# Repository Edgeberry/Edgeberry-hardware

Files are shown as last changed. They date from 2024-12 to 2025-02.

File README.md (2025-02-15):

Edgeberry banner

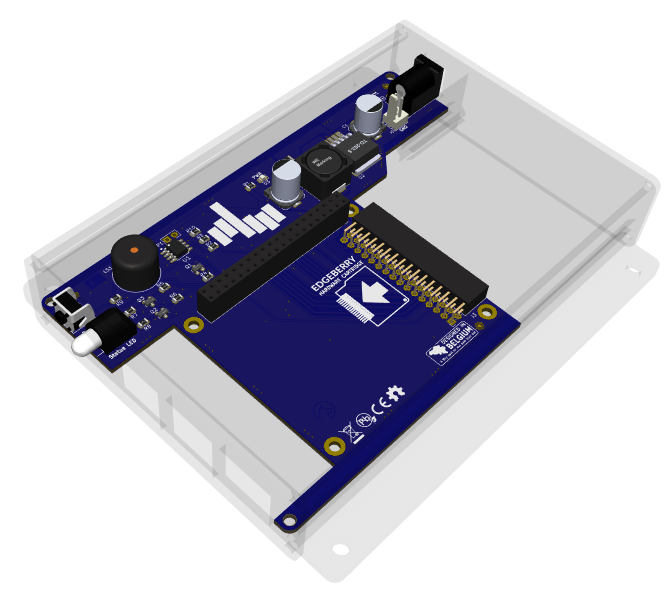
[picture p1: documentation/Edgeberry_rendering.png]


The **Edgeberry Base Board** provides essential additional functionality for deploying the Raspberry Pi Model B as an IoT edge device in a real-world environment.

- **12 to 24VDC input power supply** for reliably powering the device with up to 3A at 5V.
- **Indicators and button** for providing status feedback and device interaction
- **Expansion slot** for Edgeberry Hardware Cartridges
- **Robust enclosure** for withstanding the environmental challenges of the real world
<br/>
<br clear="right"/>

## Edgeberry Device Software
For using your Edgeberry hardware with the Edgeberry ecosystem (e.g. the Edgeberry Dashboard), you'll need to install the [Edgeberry Device Software](https://github.com/Edgeberry/Edgeberry/). Follow [these installation steps](https://github.com/Edgeberry/Edgeberry?tab=readme-ov-file#installation). If you have different plans with this board, this software is not required for correct operation of any of its hardware components.

## (re)Writing the EEPROM
>[!important]
>**When you purchased the Edgeberry Hardware, the manufacturer has written the EEPROM**. If you are the manufacturer, or you're hacking your Edgeberry board, then continue with the following steps.

1) Close the `write protection` jumper (JP1) on the Edgeberry Hardware to enable writing the EEPROM
2) Download and build the [Raspberry Pi Hat eeprom utils](https://github.com/raspberrypi/hats) on your device 
3) Make the EEPROM file from the eeprom_settings.txt using `eepmake` <br> e.g. `$ ./eepmake eeprom_settings.txt edgeberry.eep`
4) Flash the EEPROM using `eepflash.sh` <br> e.g. `$ sudo ./eepflash -w -t=24c256 -f=edgeberry.eep`
5) Now `reboot` the device and check the device tree for your hat's settings <br> e.g. `$ cat /proc/device-tree/hat/vendor`)

## License & Collaboration
**Copyright© 2024 Sanne 'SpuQ' Santens**. This project is released under the [**CERN OHL-W**](./LICENSE.txt) license. The [Rules & Guidelines](https://github.com/Edgeberry/.github/blob/main/brand/Edgeberry_Trademark_Rules_and_Guidelines.md) apply to the usage of the Edgeberry™ brand.

### Collaboration

If you'd like to contribute to this project, please follow these guidelines:
1. Fork the repository and create your branch from `main`.
2. Make your changes and ensure they adhere to the project's design style and conventions.
3. Test your changes thoroughly.
4. Ensure your commits are descriptive and well-documented.
5. Open a pull request, describing the changes you've made and the problem or feature they address.

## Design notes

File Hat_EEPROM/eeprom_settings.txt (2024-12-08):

########################################################################
# 	Edgeberry HAT - EEPROM settings
# 	by Sanne 'SpuQ' Santens
#
#	IMPORTANT:	On the Edgeberry Base Board, close the jumper (JP1)
#			to write the EEPROM! Otherwise the device is in
#			read-only mode, but the flash tool indicates successful
#			writing to the EEPROM!
# 	Usage:
#		1) Make sure the jumper (JP1) on the Edgeberry Base Board is closed
#		2) Run this file through eepmake tool
# 		3) Use eepflash tool to write to attached HAT ID EEPROM
#		4) Check the content of the EEPROM using eepdump
#
#	Edits:
#	14/05/2024	vendor		"Edgeberry"
#			product		"Edgeberry"
#			back_power	2 (Edgeberry's power supply can deliver up to 3A)
#			product_id	0x0001 (first Edgeberry product)
#			product_ver	0x0103 (first byte is major number, second byte is minor number)
#			set gpio 5 output (buzzer)
#			set gpio 6 input (button)
#			set gpio 26 output (LED green)
#			set gpio 19 output (LED red)
#			product_uuid 	left at zero to let eepmake auto-generate an RFC4122 compliant UUID
#			gpio_drive, gpio_slew, gpio_hysteresis removed due to error during making eeprom file
#	08/12/2024	product_ver	0x0107	(Hardware Revision 1.7)
#
# Resources:
#	https://forums.raspberrypi.com/viewtopic.php?t=108134
#	https://github.com/raspberrypi/hats/tree/master/eepromutils
#
########################################################################

########################################################################
# Vendor info

# 128 bit UUID. If left at zero eepmake tool will auto-generate
# RFC 4122 compliant UUID
product_uuid 00000000-0000-0000-0000-000000000000

# 16 bit product id
product_id 0x0001

# 16 bit product version
product_ver 0x0107

# ASCII vendor string  (max 255 characters)
vendor "Edgeberry"

# ASCII product string (max 255 characters)
product "Edgeberry"

########################################################################
# GPIO bank settings, set to nonzero to change from the default.
# NOTE these setting can only be set per BANK, uncommenting any of
# these will force the bank to use the custom setting.

# If board back-powers Pi via 5V GPIO header pins:
# 0 = board does not back-power
# 1 = board back-powers and can supply the Pi with a minimum of 1.3A
# 2 = board back-powers and can supply the Pi with a minimum of 2A
# 3 = reserved
# If back_power=2 then USB high current mode will be automatically 
# enabled on the Pi
back_power 2

########################################################################
# GPIO pins, uncomment for GPIOs used on board
# Options for FUNCTION: INPUT, OUTPUT, ALT0-ALT5
# Options for PULL: DEFAULT, UP, DOWN, NONE
# NB GPIO0 and GPIO1 are reserved for ID EEPROM so cannot be set
#
# Note:  The GPIO map is parsed by the Videocore bootloader prior to ARM boot and not Linux

#         GPIO  FUNCTION  PULL
#         ----  --------  ----
#setgpio  2     INPUT     DEFAULT
#setgpio  3     INPUT     DEFAULT
#setgpio  4     INPUT     DEFAULT
setgpio  5     OUTPUT     DEFAULT
setgpio  6     INPUT     DEFAULT
#setgpio  7     INPUT     DEFAULT
#setgpio  8     INPUT     DEFAULT
#setgpio  9     INPUT     DEFAULT
#setgpio  10    INPUT     DEFAULT
#setgpio  11    INPUT     DEFAULT
#setgpio  12    INPUT     DEFAULT
#setgpio  13    INPUT     DEFAULT
#setgpio  14    INPUT     DEFAULT
#setgpio  15    INPUT     DEFAULT
#setgpio  16    INPUT     DEFAULT
#setgpio  17    INPUT     DEFAULT
#setgpio  18    INPUT     DEFAULT
setgpio  19    OUTPUT     DEFAULT
#setgpio  20    INPUT     DEFAULT
#setgpio  21    INPUT     DEFAULT
#setgpio  22    INPUT     DEFAULT
#setgpio  23    INPUT     DEFAULT
#setgpio  24    INPUT     DEFAULT
#setgpio  25    INPUT     DEFAULT
setgpio  26    OUTPUT     DEFAULT
#setgpio  27    INPUT     DEFAULT

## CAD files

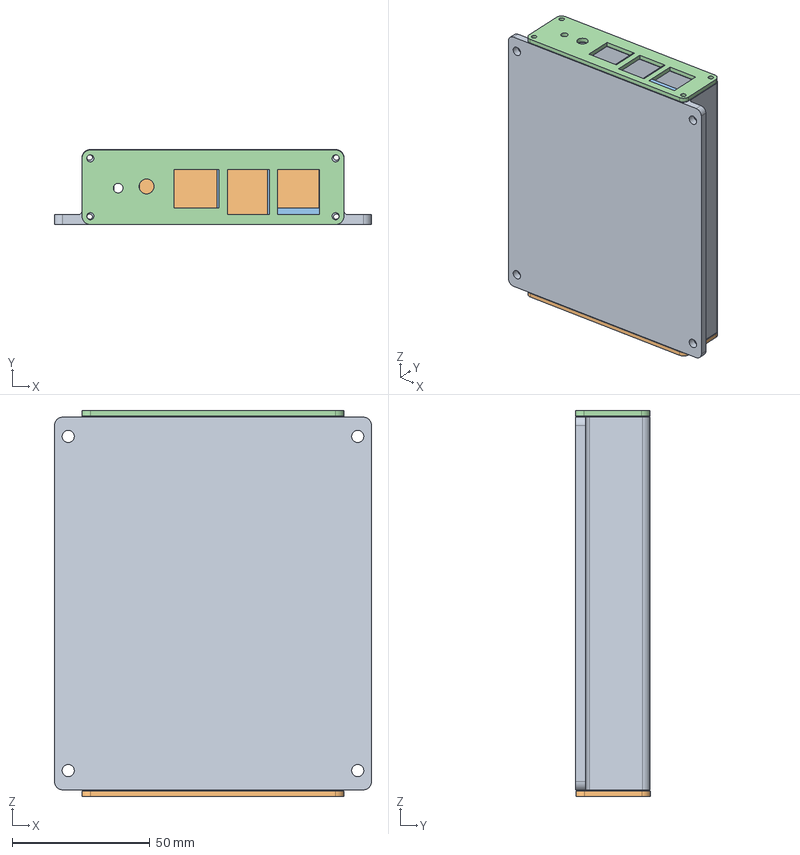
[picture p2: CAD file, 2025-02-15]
Edgeberry_Enclosure.FCStd
115.0 x 27.2 x 140.0 mm
Edgeberry_Enclosure
Faceplate_back
Faceplate_front
Faceplate_front_RPi4

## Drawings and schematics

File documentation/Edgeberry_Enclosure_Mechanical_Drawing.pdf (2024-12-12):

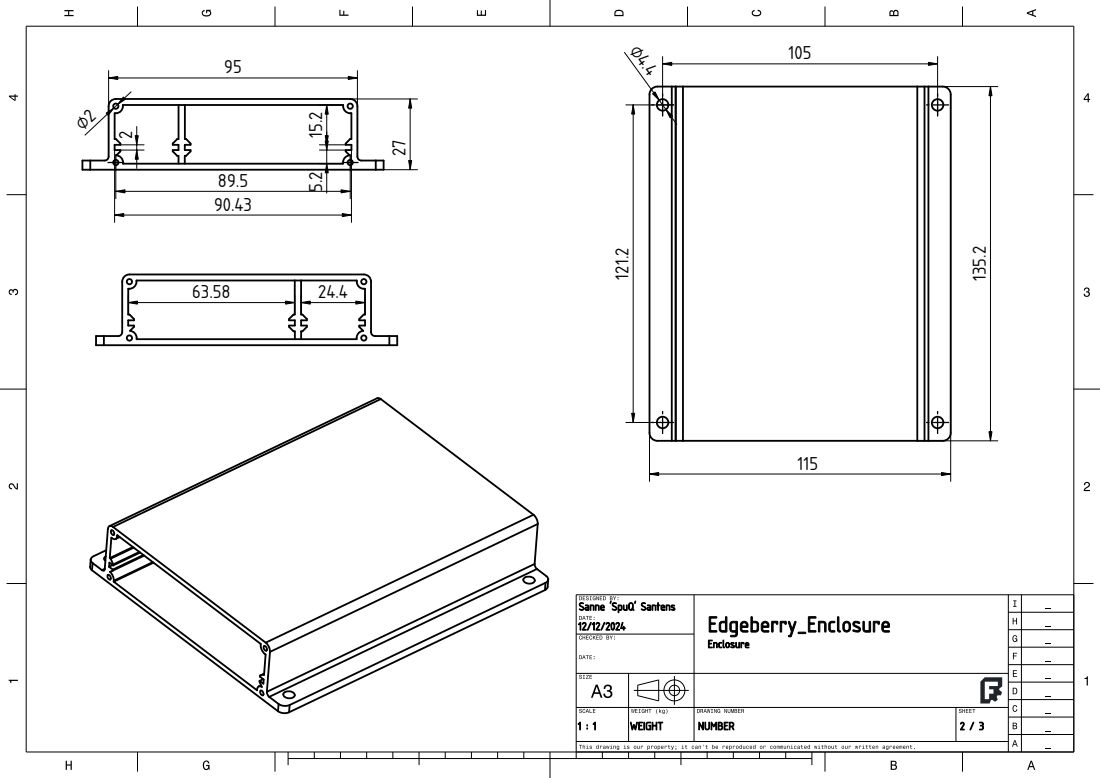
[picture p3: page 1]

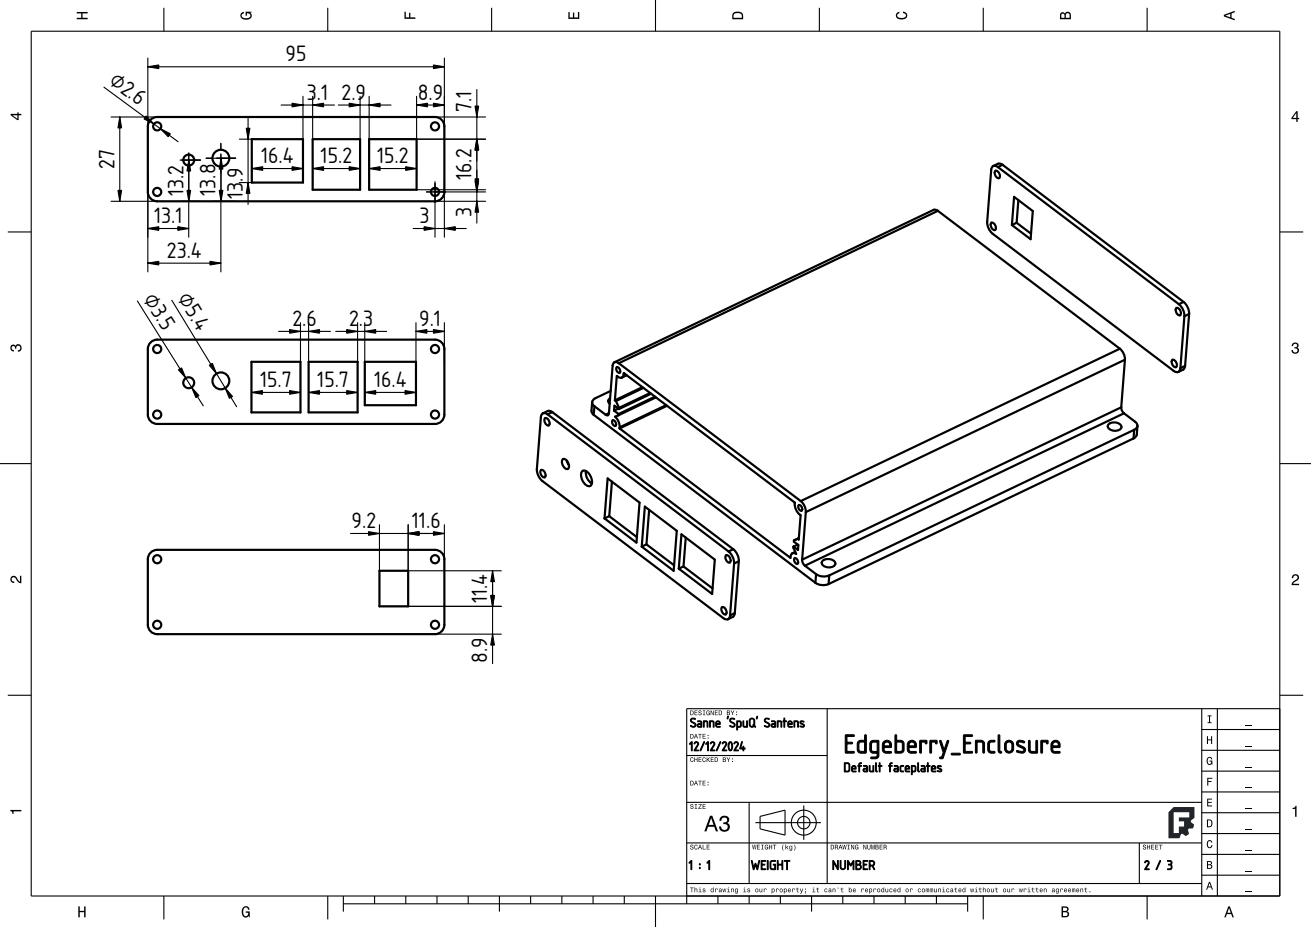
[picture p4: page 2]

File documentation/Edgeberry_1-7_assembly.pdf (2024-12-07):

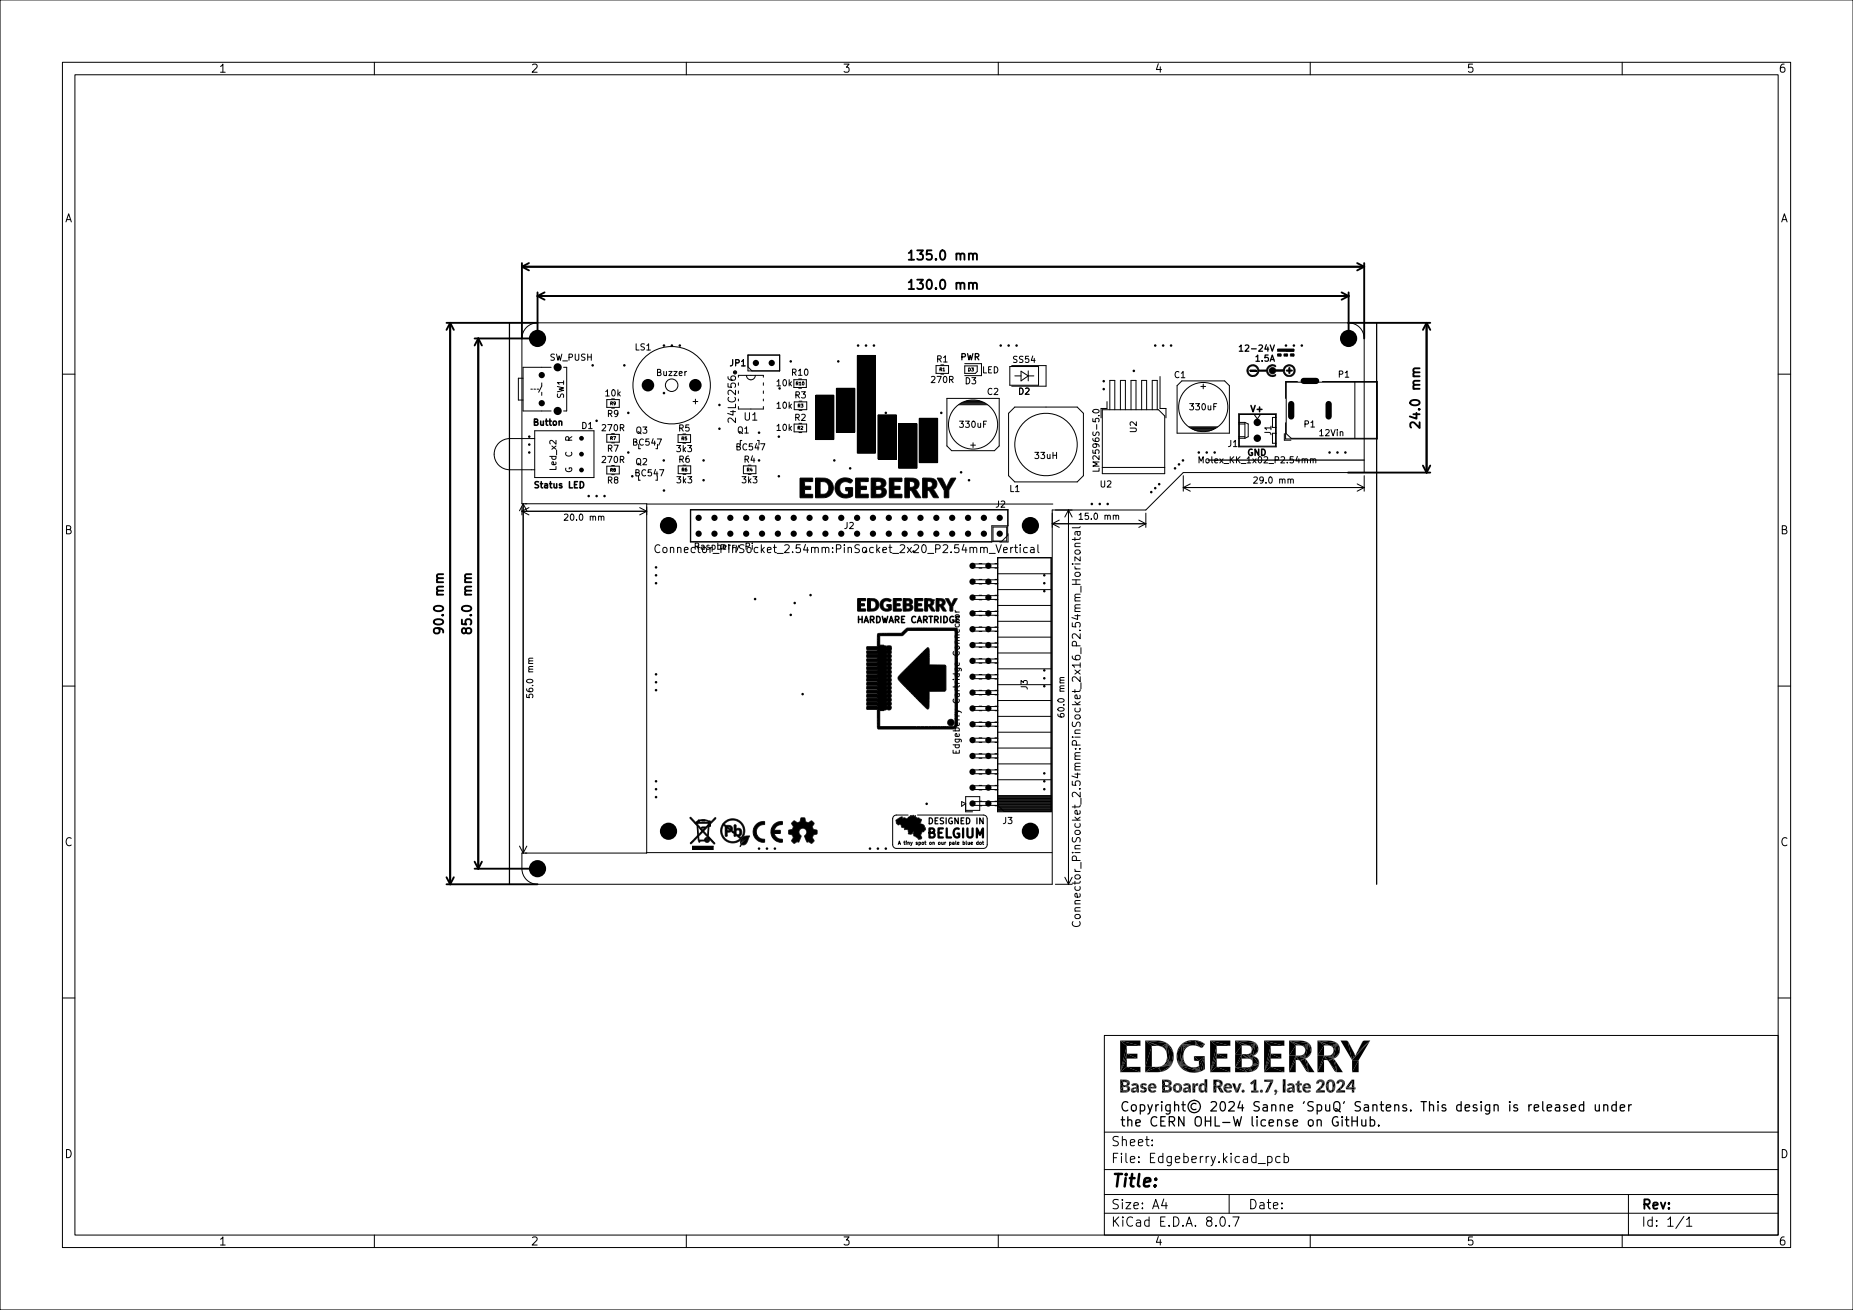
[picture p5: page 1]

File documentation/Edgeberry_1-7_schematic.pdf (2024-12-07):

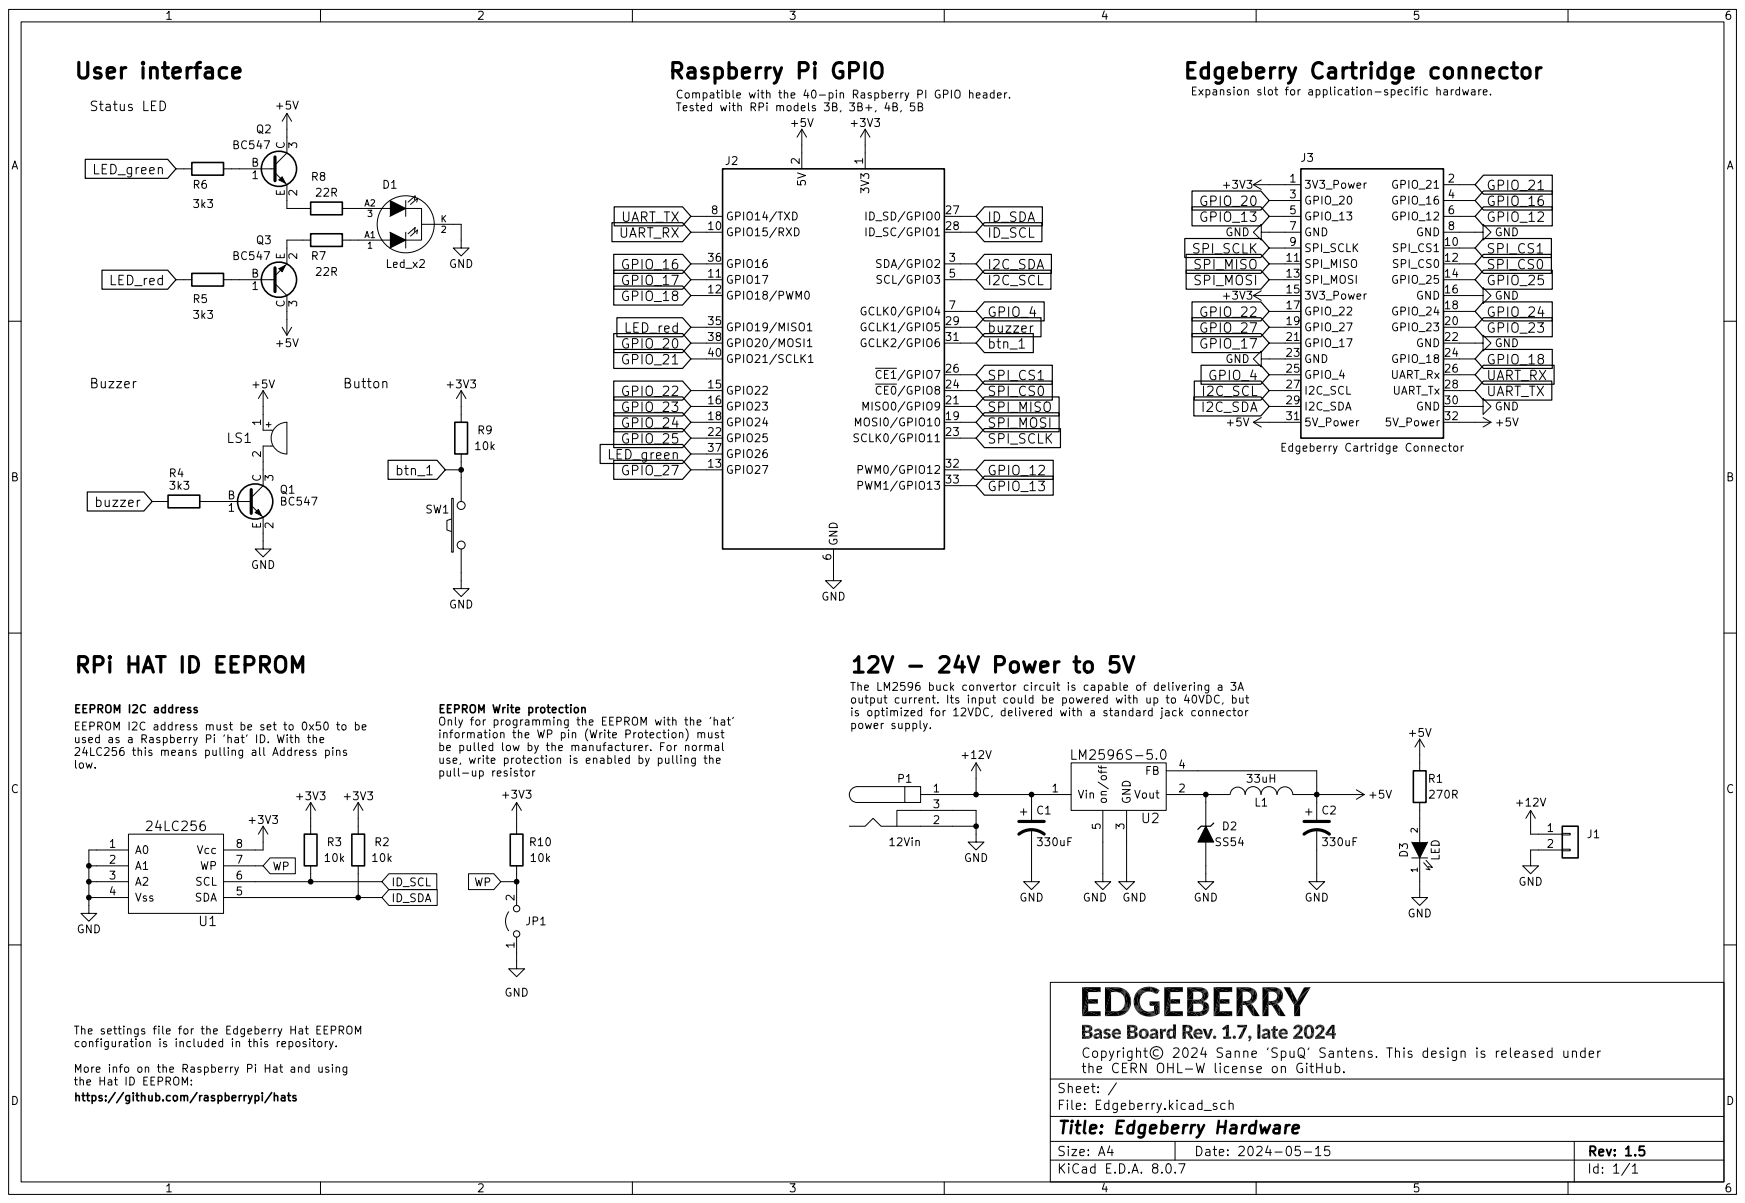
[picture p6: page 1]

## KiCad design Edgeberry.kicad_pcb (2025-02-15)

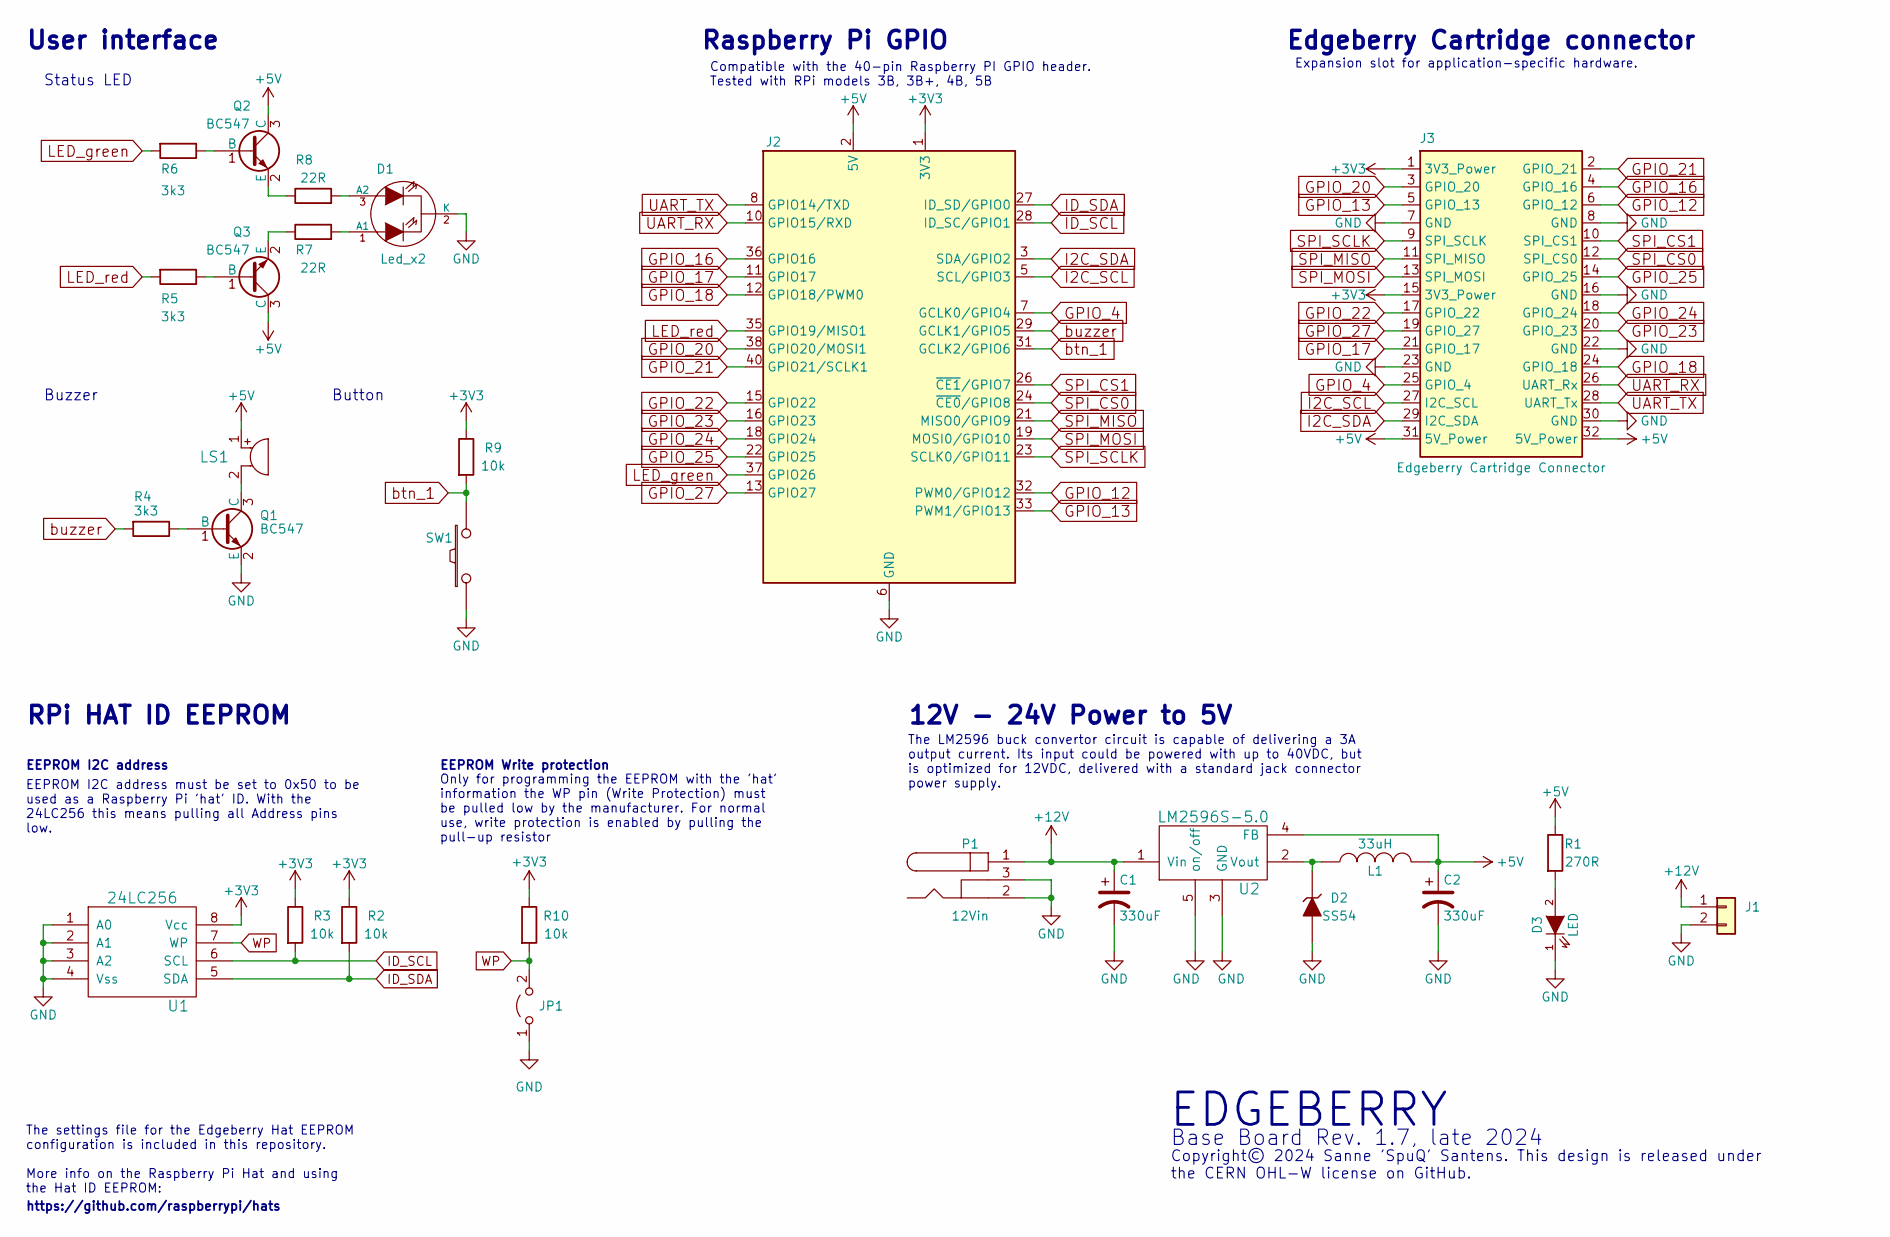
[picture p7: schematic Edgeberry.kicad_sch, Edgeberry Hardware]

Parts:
C1, C2: 330uF; c_elec_8x10
D1: Led_x2; bicolor_LED_right_angle
D2: SS54; D_SMA
D3: LED; LED_0805_2012Metric
J1: Molex_KK_1x02_P2.54mm; Molex_KK-254_AE-6410-02A_1x02_P2.54mm_Vertical
J2: Raspberry_Pi_2_3; PinSocket_2x20_P2.54mm_Vertical
J3: Edgeberry Cartridge Connector; PinSocket_2x16_P2.54mm_Horizontal
JP1: Jumper_2_Open; PinHeader_1x02_P2.54mm_Vertical
L1: 33uH; SELF-WE-PD-XXL
LS1: Buzzer; Buzzer_12x9.5RM7.6
P1: 12Vin; BarrelJack_Horizontal
Q1, Q2, Q3: BC547; SOT-23
R1: 270R; R_0805_2012Metric
R2, R3, R9, R10: 10k; R_0805_2012Metric
R4, R5, R6: 3k3; R_0805_2012Metric
R7, R8: 22R; R_0805_2012Metric
SW1: SW_PUSH; tactile_switch_vertical
U1: 24LC256; SOIC_8
U2: LM2596S-5.0; TO-263-5_TabPin3

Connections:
+3V3: J2.1 (3V3), J2.17 (3V3), J3.1 (3V3_Power), J3.15 (3V3_Power), R2.1, R3.1, R9.1, R10.1, U1.8 (Vcc)
+5V: C2.1, J2.2 (5V), J2.4 (5V), J3.31 (5V_Power), J3.32 (5V_Power), L1.2, LS1.1, Q2.3 (C), Q3.3 (C), R1.1, U2.4 (FB)
+12V: C1.1, J1.1, P1.1, U2.1 (Vin)
GND: C1.2, C2.2, D1.2 (K), D2.2 (A), D3.1 (K), J1.2, J2.6 (GND), J2.9 (GND), J2.14 (GND), J2.20 (GND), J2.25 (GND), J2.30 (GND), J2.34 (GND), J2.39 (GND), J3.7 (GND), J3.8 (GND), J3.16 (GND), J3.22 (GND), J3.23 (GND), J3.30 (GND), JP1.1 (A), P1.2, P1.3, Q1.2 (E), SW1.1, U1.1 (A0), U1.2 (A1), U1.3 (A2), U1.4 (Vss), U2.3 (GND), U2.5 (on/off)
GPIO_4: J2.7 (GCLK0/GPIO4), J3.25 (GPIO_4)
GPIO_12: J2.32 (PWM0/GPIO12), J3.6 (GPIO_12)
GPIO_13: J2.33 (PWM1/GPIO13), J3.5 (GPIO_13)
GPIO_16: J2.36 (GPIO16), J3.4 (GPIO_16)
GPIO_17: J2.11 (GPIO17), J3.21 (GPIO_17)
GPIO_18: J2.12 (GPIO18/PWM0), J3.24 (GPIO_18)
GPIO_20: J2.38 (GPIO20/MOSI1), J3.3 (GPIO_20)
GPIO_21: J2.40 (GPIO21/SCLK1), J3.2 (GPIO_21)
GPIO_22: J2.15 (GPIO22), J3.17 (GPIO_22)
GPIO_23: J2.16 (GPIO23), J3.20 (GPIO_23)
GPIO_24: J2.18 (GPIO24), J3.18 (GPIO_24)
GPIO_25: J2.22 (GPIO25), J3.14 (GPIO_25)
GPIO_27: J2.13 (GPIO27), J3.19 (GPIO_27)
I2C_SCL: J2.5 (SCL/GPIO3), J3.27 (I2C_SCL)
I2C_SDA: J2.3 (SDA/GPIO2), J3.29 (I2C_SDA)
ID_SCL: J2.28 (ID_SC/GPIO1), R3.2, U1.6 (SCL)
ID_SDA: J2.27 (ID_SD/GPIO0), R2.2, U1.5 (SDA)
LED_green: J2.37 (GPIO26), R6.2
LED_red: J2.35 (GPIO19/MISO1), R5.2
unnamed: D1.1 (A1), R7.2
unnamed: D1.3 (A2), R8.2
unnamed: D2.1 (K), L1.1, U2.2 (Vout)
unnamed: D3.2 (A), R1.2
unnamed: Q1.1 (B), R4.1
unnamed: LS1.2, Q1.3 (C)
unnamed: Q2.1 (B), R6.1
unnamed: Q2.2 (E), R8.1
unnamed: Q3.1 (B), R5.1
unnamed: Q3.2 (E), R7.1
SPI_CS0: J2.24 (~CE0/GPIO8), J3.12 (SPI_CS0)
SPI_CS1: J2.26 (~CE1/GPIO7), J3.10 (SPI_CS1)
SPI_MISO: J2.21 (MISO0/GPIO9), J3.11 (SPI_MISO)
SPI_MOSI: J2.19 (MOSI0/GPIO10), J3.13 (SPI_MOSI)
SPI_SCLK: J2.23 (SCLK0/GPIO11), J3.9 (SPI_SCLK)
UART_RX: J2.10 (GPIO15/RXD), J3.26 (UART_Rx)
UART_TX: J2.8 (GPIO14/TXD), J3.28 (UART_Tx)
WP: JP1.2 (B), R10.2, U1.7 (WP)
btn_1: J2.31 (GCLK2/GPIO6), R9.2, SW1.2
buzzer: J2.29 (GCLK1/GPIO5), R4.2

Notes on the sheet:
Copyright© 2024 Sanne 'SpuQ' Santens. This design is released under the CERN OHL-W license on GitHub.
Button
Base Board Rev. 1.7, late 2024
EEPROM I2C address must be set to 0x50 to be used as a Raspberry Pi 'hat' ID. With the 24LC256 this means pulling all Address pins low.
User interface
12V - 24V Power to 5V
EEPROM Write protection
Raspberry Pi GPIO
RPi HAT ID EEPROM
https://github.com/raspberrypi/hats
The settings file for the Edgeberry Hat EEPROM configuration is included in this repository. More info on the Raspberry Pi Hat and using the Hat ID EEPROM:
The LM2596 buck convertor circuit is capable of delivering a 3A output current. Its input could be powered with up to 40VDC, but is optimized for 12VDC, delivered with a standard jack connector power supply.
Only for programming the EEPROM with the 'hat' information the WP pin (Write Protection) must be pulled low by the manufacturer. For normal use, write protection is enabled by pulling the pull-up resistor
Buzzer
Status LED
EDGEBERRY
Expansion slot for application-specific hardware.
Edgeberry Cartridge connector
EEPROM I2C address
Compatible with the 40-pin Raspberry PI GPIO header. Tested with RPi models 3B, 3B+, 4B, 5B

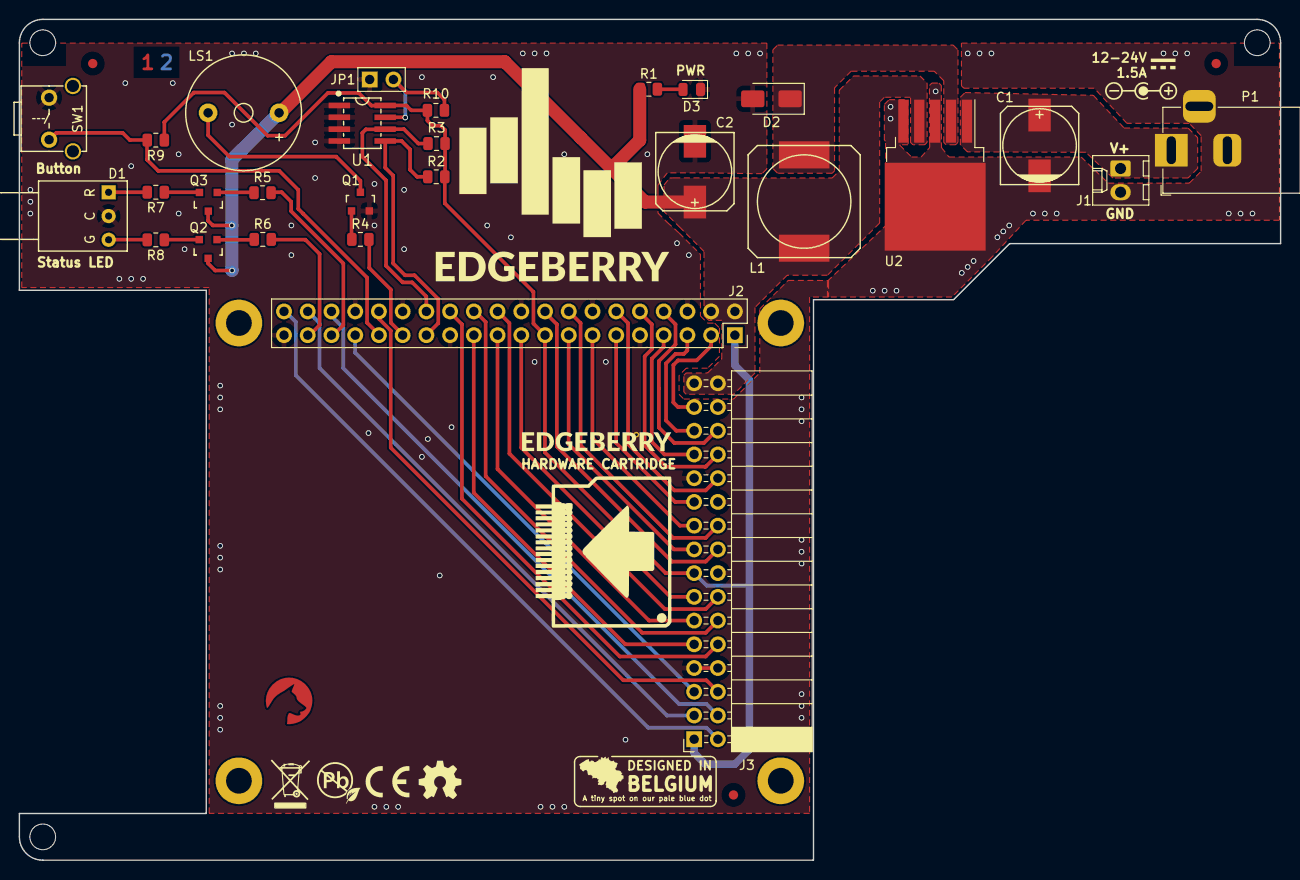
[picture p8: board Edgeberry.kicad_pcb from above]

Board: 2 copper layers, 135.0 x 90.0 mm, 28 parts (0 on the bottom side), 43 nets.

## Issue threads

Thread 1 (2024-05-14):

Hat EEPROM write protection

SpuQ, 2024-05-14:
In version **1.2**, the ID EEPROM's Write pin is connected to ground, which consistenly enables the EEPROM to be able to be overwritten and could lead to accidental overwriting of the 'Hat' information. This should be protected by using a pull-up resistor to the +3v3 power and, for example, a jumper to GND.

Closed 2024-05-16.

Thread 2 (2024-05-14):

Back-powering reverse current blocking diode

SpuQ, 2024-05-14:
reverse current blocking diode (ZVD) should be added to the circuit for back-powering the Raspberry Pi

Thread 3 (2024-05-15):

Buck convertor capacitors optimization for 12VDC input

SpuQ, 2024-05-15:
The design currently uses 220uF/35V aluminum capacitors in the buck convertor circuit. According to the [LM2596S-5.0](https://mm.digikey.com/Volume0/opasdata/d220001/medias/docus/2577/UMW%20LM2596_HV.pdf) datasheet (page 7) when using a maximum input voltage of 15VDC, 330uF/35V is recommended.

Closed 2024-05-16.

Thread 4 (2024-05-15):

Status LED on 5V power instead of 3V3

SpuQ, 2024-05-15:
Reviewing the circuit, I feel like I designed the bi-color status led circuit to power the LEDs by 5V instead of 3V3 as it is now.

Closed 2024-05-16.

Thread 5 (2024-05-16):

Raspberry Pi connector is 'on bottom', but it's not

SpuQ, 2024-05-16:
Somewhere early in the design proces, I did something wrong with the 40-pin connector for the Raspberry Pi. It's 'on the bottom' in the PCB in the 'component positions' file.

SpuQ, 2024-05-18:
Redesigned the schematic and PCB with the correct symbols for the Raspberry Pi GPIO header. Issue solved!

Closed 2024-05-18.

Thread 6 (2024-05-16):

Every via has a 'REF***' and a 'component position'

SpuQ, 2024-05-16:
Somewhere early in the process, while using a way older version of KiCad, for some reason I must have made a component of my via's. But now they appear in the component position files etc as components. Not really clean, right. Should be fixed.

SpuQ, 2024-05-18:
Replaced all via's with actual via's. Problem solved

Closed 2024-05-18.

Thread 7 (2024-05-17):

Ability to use 12V on a Cartridge

SpuQ, 2024-05-17:
The **Edgeberry Hardware Cartridge** has access to the Raspberry Pi's 3V3, and the on-board buck convertor's 5V, but it would be nice to have **access to the 12V** that is supplied to the Edgeberry board.

SpuQ, 2024-05-17:
**Solved in rev1.3** by putting a [2Pin Molex connector](https://www.molex.com/en-us/products/part-detail/0022232021) on the 12V power supply, so with [an extra wire](https://mybatteryplus.com.au/products/molex-type-22-01-1023-formerly-5051-2-e-5051-2m-leads-red-black-75mm-6mm-strip-tin-awg24) 12V can supplied to the Cartridge.

SpuQ, 2024-05-17:
Solved in rev1.3 by putting a [2Pin Molex connector](https://www.molex.com/en-us/products/part-detail/0022232021) on the 12V power supply, so with [an extra wire](https://mybatteryplus.com.au/products/molex-type-22-01-1023-formerly-5051-2-e-5051-2m-leads-red-black-75mm-6mm-strip-tin-awg24) 12V can supplied to the Cartridge.

Closed 2024-05-17.

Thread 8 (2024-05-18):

Power outage - graceful shutdown

SpuQ, 2024-05-18:
It would be great if the device didn't just 'drop dead' on a power outage; if there was a circuit that notified the Raspberry pi that power was cut so it can stop it's activities gracefully, log a power cut event, and shutdown until power comes back on.

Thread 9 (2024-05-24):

Mechanical holes PTH instead of NPTH

SpuQ, 2024-05-24:
While manufacturing the prototypes, the manufacturer has let me know they prefer plated through (PTH) holes over non-plated through (NPTH) holes for production - even for mechanical holes. Confirm whether this is a universal thing, and adapt all 7 mechanical holes in the design to PTH.

The NPTH holes in the prototypes of v1.5 will be manufactured plated through.

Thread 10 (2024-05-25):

Polarity protection 12V in

SpuQ, 2024-05-25:
Not all barrel jack power supplies have the + side on the pin and the - side on the outside of the connector. Add polarity protection to prevent accidents.

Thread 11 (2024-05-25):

Status LED driver circuit issue

SpuQ, 2024-05-25:
Because these LEDs have a common anode, they are connected to the emittor of the BC847 transistors. The voltage on the collector of an NPN transistor can only be V(b)- 0,7V. The current circuit is very limiting for the current flowing through the LEDs.

Better would be a FET instead of a transistor (with pull-up resistor at the gate), and an open-drain output.

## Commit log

2024-05-14 Edgeberry v1.2 on GitHub
    [EdgeBerry.kicad_pcb, EdgeBerry.kicad_sch]
2024-05-15 Schematic: in-schematic todo's moved to GitHub issues
    [EdgeBerry.kicad_sch]
2024-05-15 Schematic: cleanup + increased readability
    [EdgeBerry.kicad_pcb, EdgeBerry.kicad_sch]
2024-05-15 Update file naming
    [Edgeberry.kicad_pcb, Edgeberry.kicad_sch]
2024-05-15 ReadMe: assembly instructions
2024-05-15 ReadMe: banner update + Device assembly text
2024-05-16 Buck convertor capacitors updated to 330uF
    [Edgeberry.kicad_sch]
2024-05-16 EEPROM write protection circuit + update version to 1.3
    [Edgeberry.kicad_pcb, Edgeberry.kicad_sch]
2024-05-16 Board: aesthetic improvements
2024-05-16 Status LED on 5V instead of 3V3 + silkscreen aesthetics
    [Edgeberry.kicad_pcb, Edgeberry.kicad_sch]
2024-05-16 Board: last pre-manufacturing adaptations
    [Edgeberry.kicad_pcb]
2024-05-17 Added a Molex 2Pin header on 12V
    [Edgeberry.kicad_pcb, Edgeberry.kicad_sch]
2024-05-17 Board: improvements for fabrications
    [Edgeberry.kicad_pcb]
2024-05-17 Board: improvements for fabrications + assembly guide
    [Edgeberry.kicad_pcb]
2024-05-18 Bugfix RPi footprint + via's are via's now instead footprints. KiCad * update.
    [Edgeberry.kicad_pcb, Edgeberry.kicad_sch]
2024-05-19 cleanup + documentation
    [Edgeberry.kicad_sch]
2024-05-19 Open Source Hardware license: CERN-OHL-W
    [Edgeberry.kicad_pcb, Edgeberry.kicad_sch]
2024-05-22 Buck convertor: Schottky diode footprint modification
    [Edgeberry.kicad_pcb, Edgeberry.kicad_sch]
2024-05-29 Bugfix: R7 and R8 lower resistors as temp fix
    [Edgeberry.kicad_sch]
2024-06-25 ReadMe: Device software guide
2024-08-25 ReadMe: Tindie button
2024-08-30 Edgeberry enclosure FreeCAD design
    [Edgeberry_Enclosure.FCStd]
2024-08-31 Documentation: Enclosure Mechanical Drawing
2024-12-07 Edgeberry rev1.7
    [Edgeberry.kicad_pcb, Edgeberry.kicad_sch]
2024-12-08 Enclosure: Raspberry Pi 3B/3B+/5B faceplate improvement
    [Edgeberry_Enclosure.FCStd]
2024-12-08 Enclosure: optimizations for Rev. 1.7
    [Edgeberry_Enclosure.FCStd]
2024-12-12 Enclosure: Mechanical drawing update
    [Edgeberry_Enclosure.FCStd]
2024-12-22 ReadMe: removed assembly info
2025-02-15 Cleanup: enclosure
    [Edgeberry.kicad_pcb, Edgeberry_Enclosure.FCStd]
